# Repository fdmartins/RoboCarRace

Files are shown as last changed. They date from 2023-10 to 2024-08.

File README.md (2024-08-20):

# Construção de um Carro Autônomo - RoboCarRace
Veiculo Autonomo OpenSource

Este é o repositório oficial do RoboCar Race, o objetivo é disponibilizar dicas, circuitos e códigos para que você construa seu veículo autônomo em escala do zero.

* Conheça mais sobre a competição em:  
https://www.robocarrace.com.br/

* Veja os vídeos detalhados da construção do carro na playlist do YouTube: 
https://www.youtube.com/playlist?list=PLqjsxWOL0TM39jP3NmErrgpj0gdBl9_DG

### Divisão do projeto
Este projeto está separado por funcionalidades. 
- Parte 1: Codigo para comunicar com multiplos sensores de ultrassom genérico HC-SR04
- Parte 2: Codigo para controlar um servo motor, geralmente usado para o controle de direção em carros de radio controle.
- Parte 3: Codigo para controlar uma controladora ESC. O ESC é um dispositivo usado para controlar motores do tipo brushless (sem escovas) de 3 fios.
- Parte 4: Este código serve para coletar dados da pista. É feito um video e um arquivo csv. Cada linha o CSV é um frame e a posição da direção, velocidade e leituras de distancia do ultrassom.
- Parte 5: Este codigo é uma versão funcional que usa segmentação simples da pista, roda apenas em nivel de CPU, portanto, em qualquer plataforma como Raspberry Pi.

### Problemas de leitura/ruídos com o sensor de ultrassom?
veja este vídeo: https://www.youtube.com/watch?v=t73wGzd_4aE

---
### Custos da Plataforma básica:
- Chassis Usado Escala 1/8 (com servo e sem motor) : R$ 600,00
- Motor Brushless 3670 2150KV Genérico: R$ 109,12
- ESC 120A Genérico: R$ 87,15
- Sensor de Ultrassom HC-SR04: R$ 15,00 (cada unidade)
- Step Down Ajustável Dc/dc 5A C/ Display Xl4015: R$ 30,00
- Raspberry Pi PICO RP2040: R$ 59,00
- Conversor de Nível Lógico Bidirecional de 4 canais: R$ 8,00
- Rádio Controle + Receptor FlySky FSGT3B (opcional, mas útil para treinamento e testes): R$ 400,00
- Bateria Lipo 2500mah 3s 11.1v 40c:  R$ 190,00

Total da plataforma: R$ 1.528,27
Total sem rádio controle: R$ 1.128,27

## Custos com Placa de controle
- Nvidia® Jetson Nano 2gb Developer Kit Versão s/ Wifi: R$ 850,00

Custo Total Completo: R$ 2.378,27

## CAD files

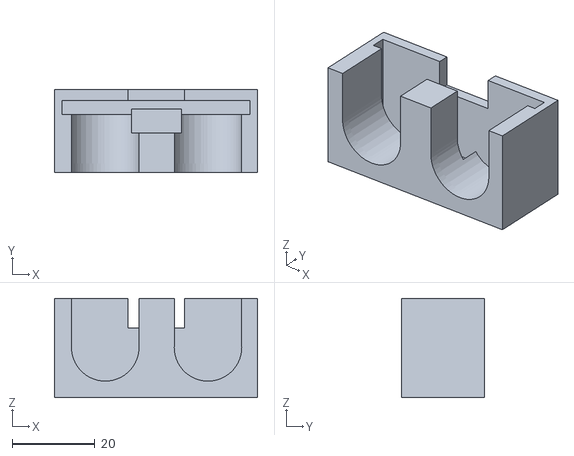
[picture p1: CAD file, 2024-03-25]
Parte 1 - Sensor Ultrassom/caixa_hcsr04_stl_3d.stl
49.0 x 20.0 x 24.0

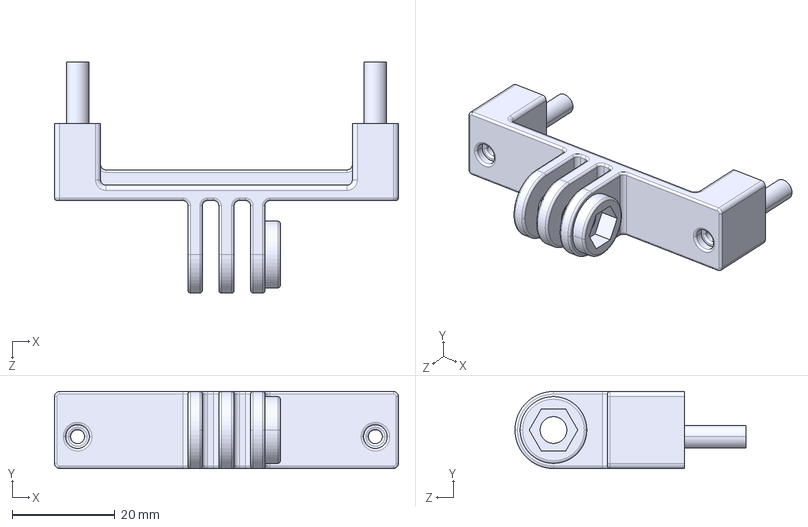
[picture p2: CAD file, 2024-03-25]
STLs - Impressão 3D/jetsoncamera/files/Camera_Mount.STEP
67.0 x 15.0 x 45.0 mm

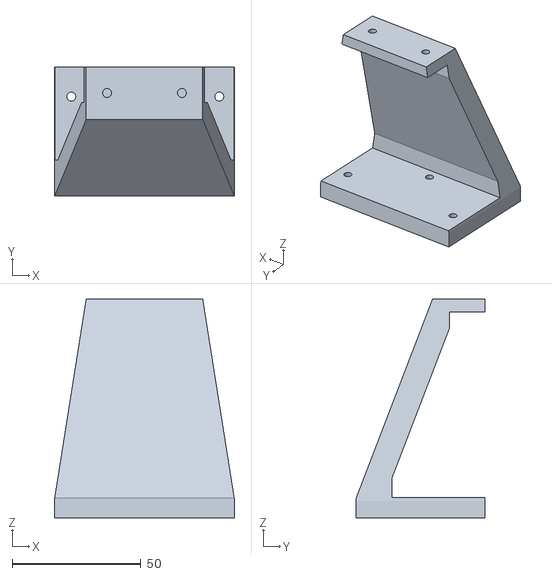
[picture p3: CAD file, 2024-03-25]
STLs - Impressão 3D/suporte_camera_3dprinter.stl
70.0 x 50.0 x 85.0

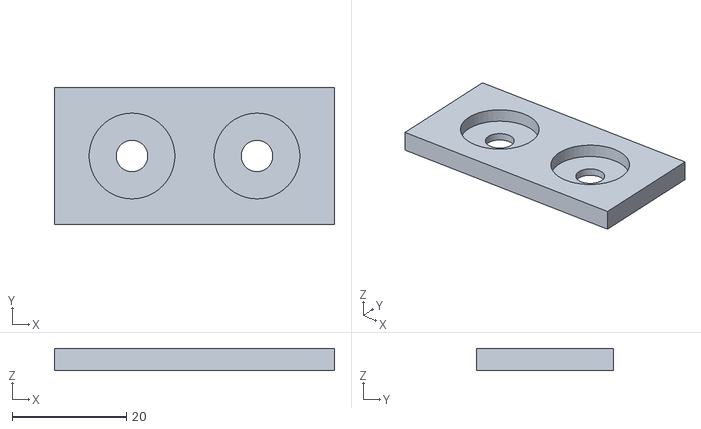
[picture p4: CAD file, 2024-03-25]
Parte 1 - Sensor Ultrassom/suporte_amortecedor_ultrassom.stl
49.0 x 24.0 x 3.90

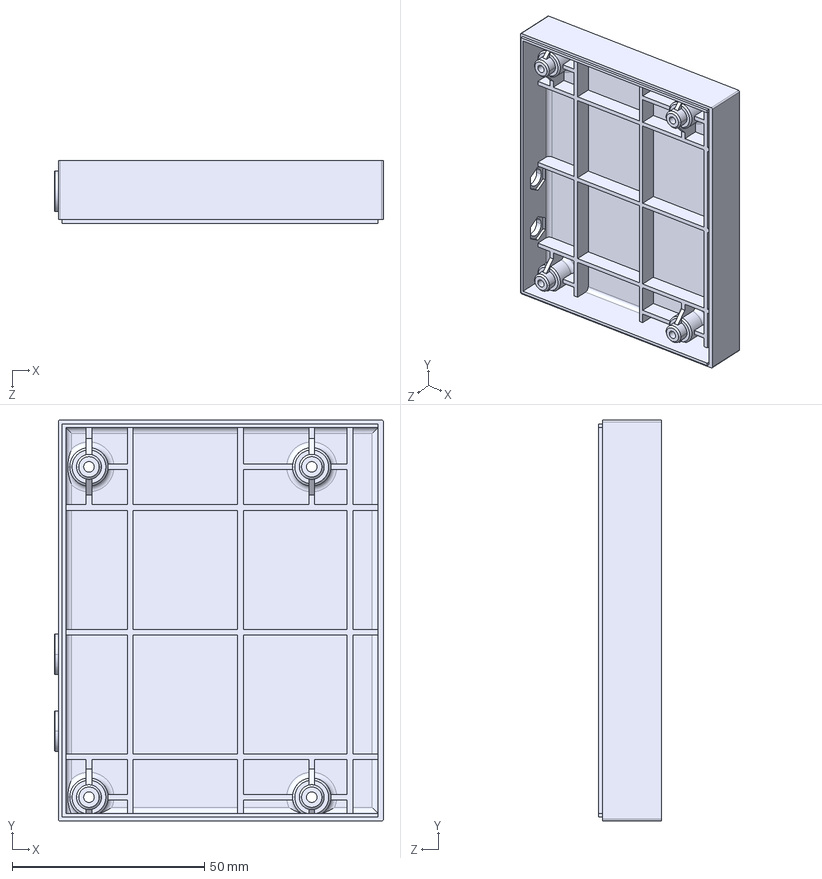
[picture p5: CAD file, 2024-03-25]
STLs - Impressão 3D/jetsoncamera/files/Case_Bottom.STEP
85.7 x 104.4 x 16.4 mm

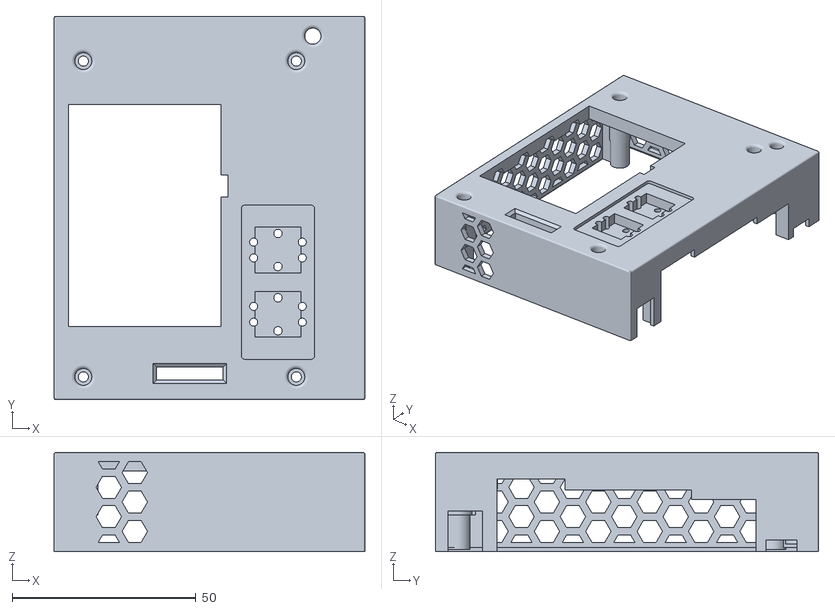
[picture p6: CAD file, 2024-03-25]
STLs - Impressão 3D/jetsoncamera/files/Case_topJetson_Case.STL
84.7 x 104.4 x 27.0

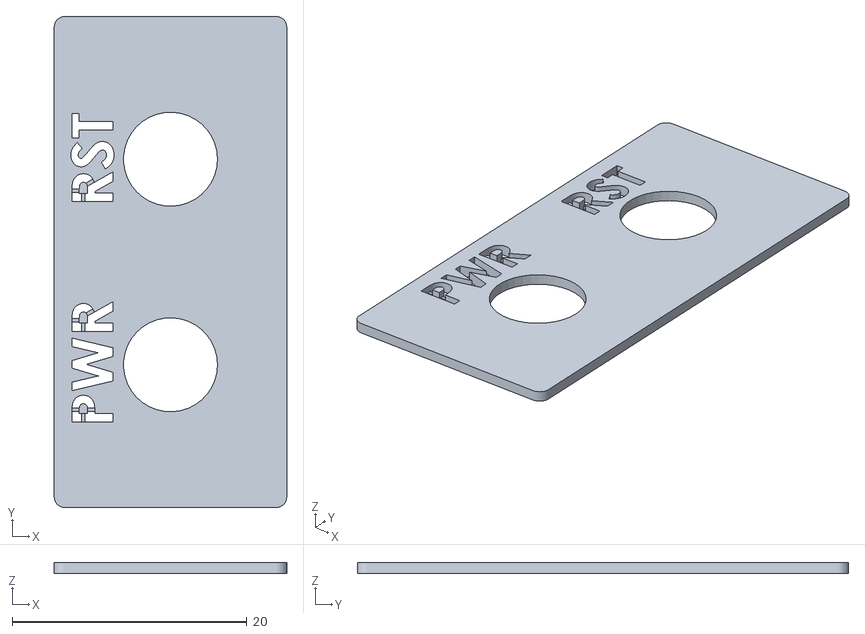
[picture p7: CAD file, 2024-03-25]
STLs - Impressão 3D/jetsoncamera/files/labelJetson_Case.STL
19.8 x 41.8 x 0.9

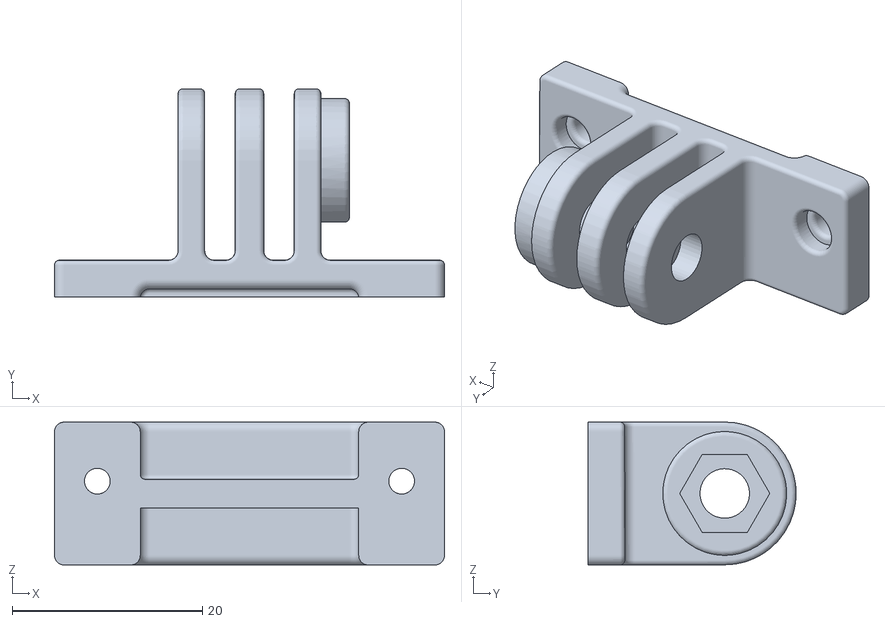
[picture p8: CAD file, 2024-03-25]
STLs - Impressão 3D/jetsoncamera/files/Camera_mount2.stl
41.0 x 21.9 x 15.0

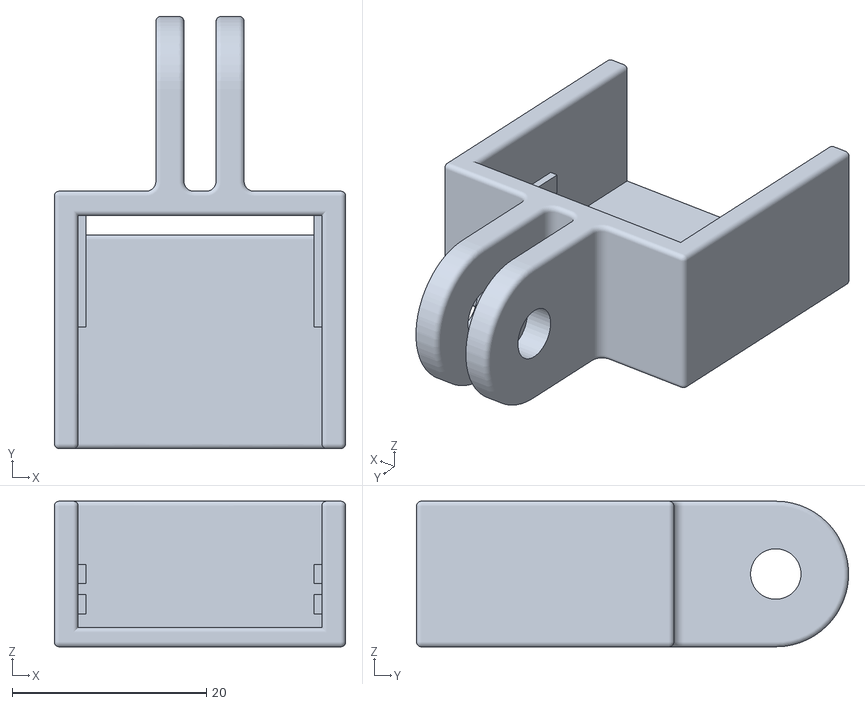
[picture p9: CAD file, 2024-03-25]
STLs - Impressão 3D/jetsoncamera/files/Camera_frameJetson_Case.STL
30.0 x 44.5 x 15.0

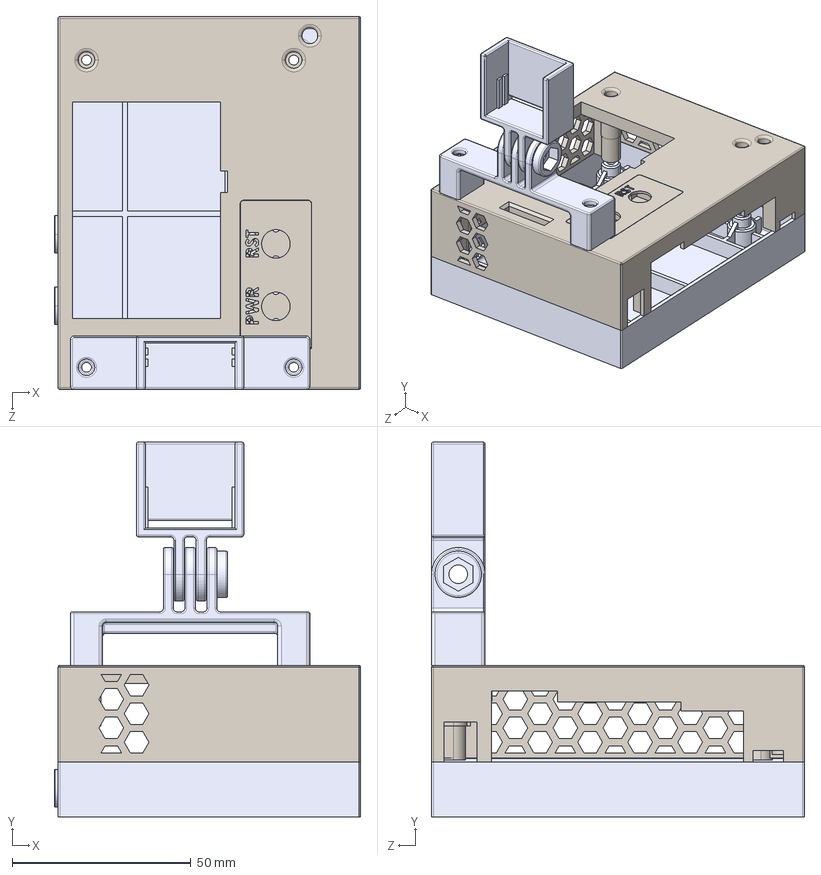
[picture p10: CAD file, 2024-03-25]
STLs - Impressão 3D/jetsoncamera/files/Jetson_Case.STEP
85.7 x 104.9 x 104.4 mm
Case_bottom^Jetson Case
Case_top^Jetson Case
Button_label^Jetson Case
Camera_mount^Jetson Case
Camera_frame^Jetson Case

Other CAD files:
STLs - Impressão 3D/jetsoncamera/files/Camera_mountJetson_Case.STL
STLs - Impressão 3D/jetsoncamera/files/Case_Label.STEP
STLs - Impressão 3D/jetsoncamera/files/Case_bottomJetson_Case.STL
STLs - Impressão 3D/jetsoncamera/files/Case_Top.STEP
STLs - Impressão 3D/jetsoncamera/files/Camera_Frame.STEP

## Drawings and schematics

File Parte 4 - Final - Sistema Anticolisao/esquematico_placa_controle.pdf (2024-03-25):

## PARACHOQUE

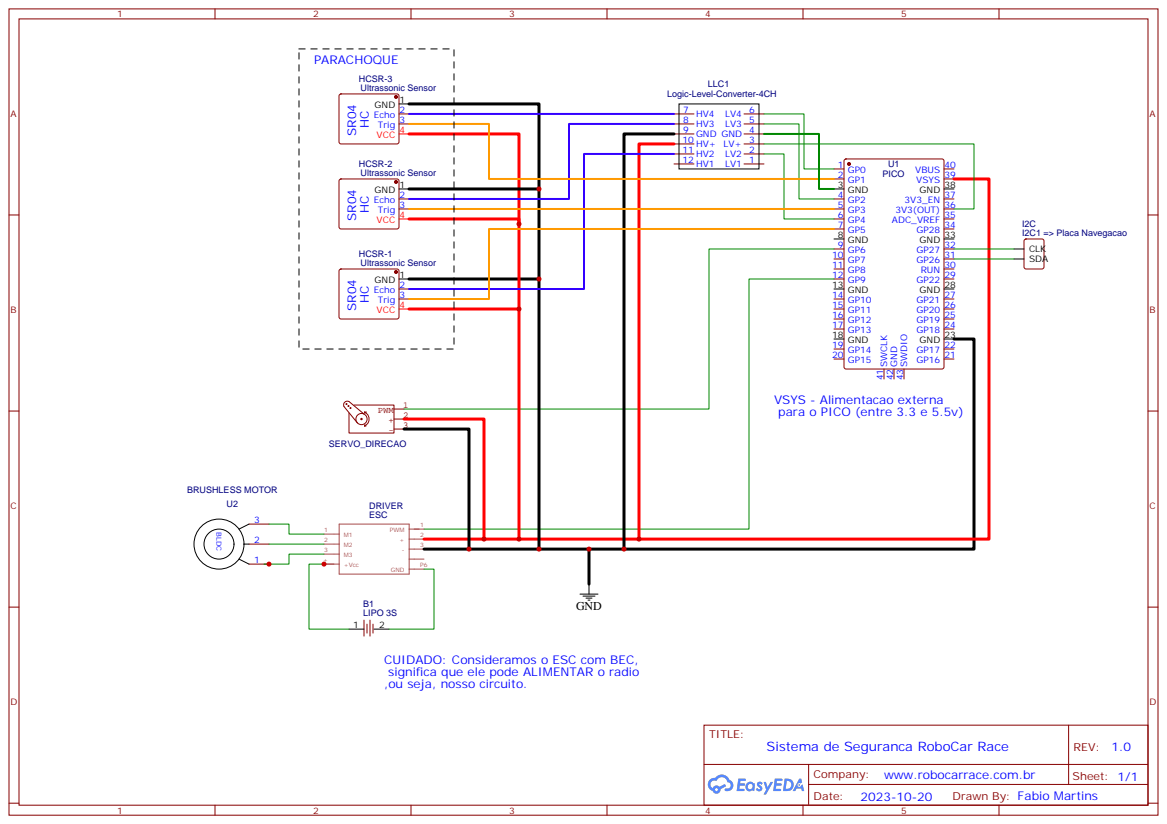
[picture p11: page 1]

CUIDADO: Consideramos o ESC com BEC,
significa que ele pode ALIMENTAR o radio
,ou seja, nosso circuito.

Company: www.robocarrace.com.br

Drawn By: Fabio Martins

## VSYS - Alimentacao externa para o PICO (entre 3.3 e 5.5v)

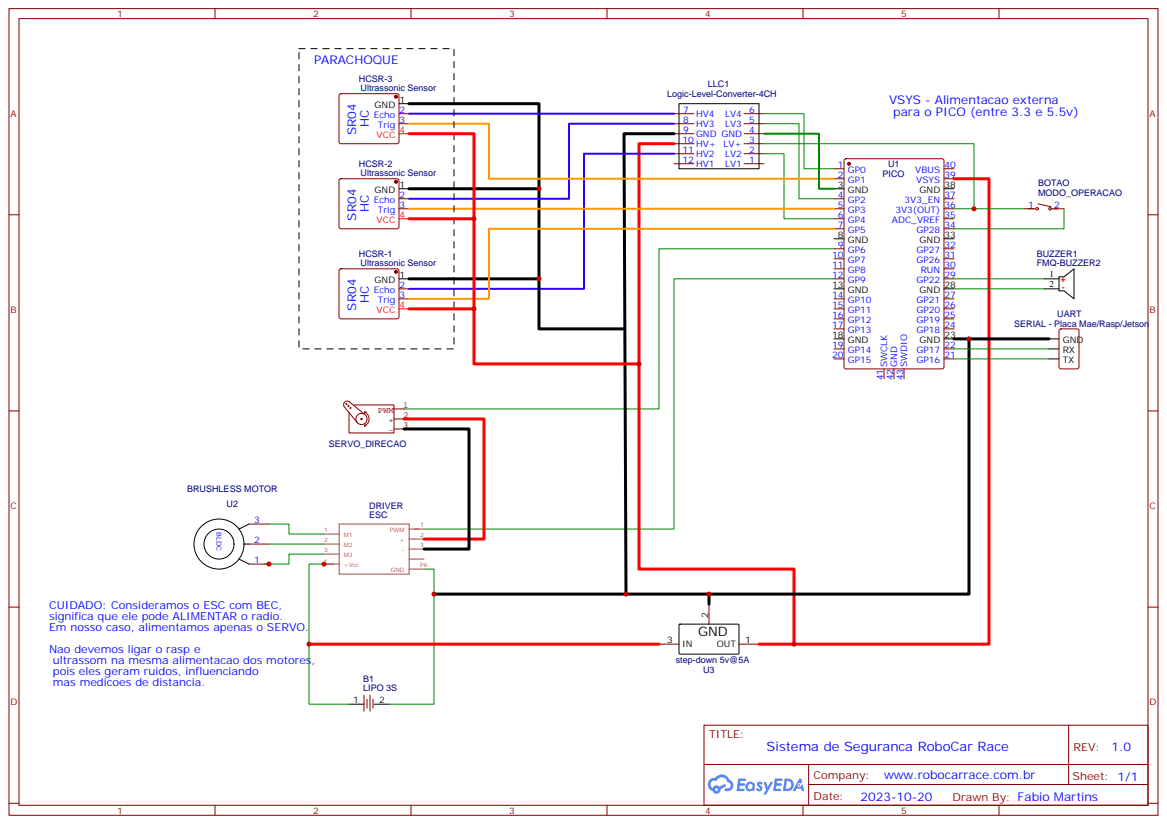
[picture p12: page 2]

SERIAL - Placa Mae/Rasp/Jetson

CUIDADO: Consideramos o ESC com BEC,
significa que ele pode ALIMENTAR o radio.
Em nosso caso, alimentamos apenas o SERVO.
Nao devemos ligar o rasp e
ultrassom na mesma alimentacao dos motores,
pois eles geram ruidos, influenciando

Company: www.robocarrace.com.br

Drawn By: Fabio Martins

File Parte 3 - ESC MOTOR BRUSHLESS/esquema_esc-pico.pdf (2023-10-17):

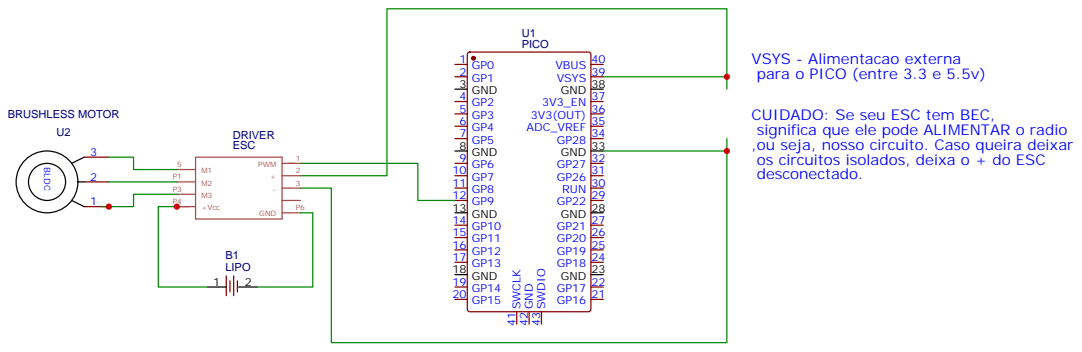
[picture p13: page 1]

CUIDADO: Se seu ESC tem BEC,
significa que ele pode ALIMENTAR o radio
,ou seja, nosso circuito. Caso queira deixar
os circuitos isolados, deixa o + do ESC
desconectado.

Company: www.robocarrace.com.br

Drawn By: F bio Martins

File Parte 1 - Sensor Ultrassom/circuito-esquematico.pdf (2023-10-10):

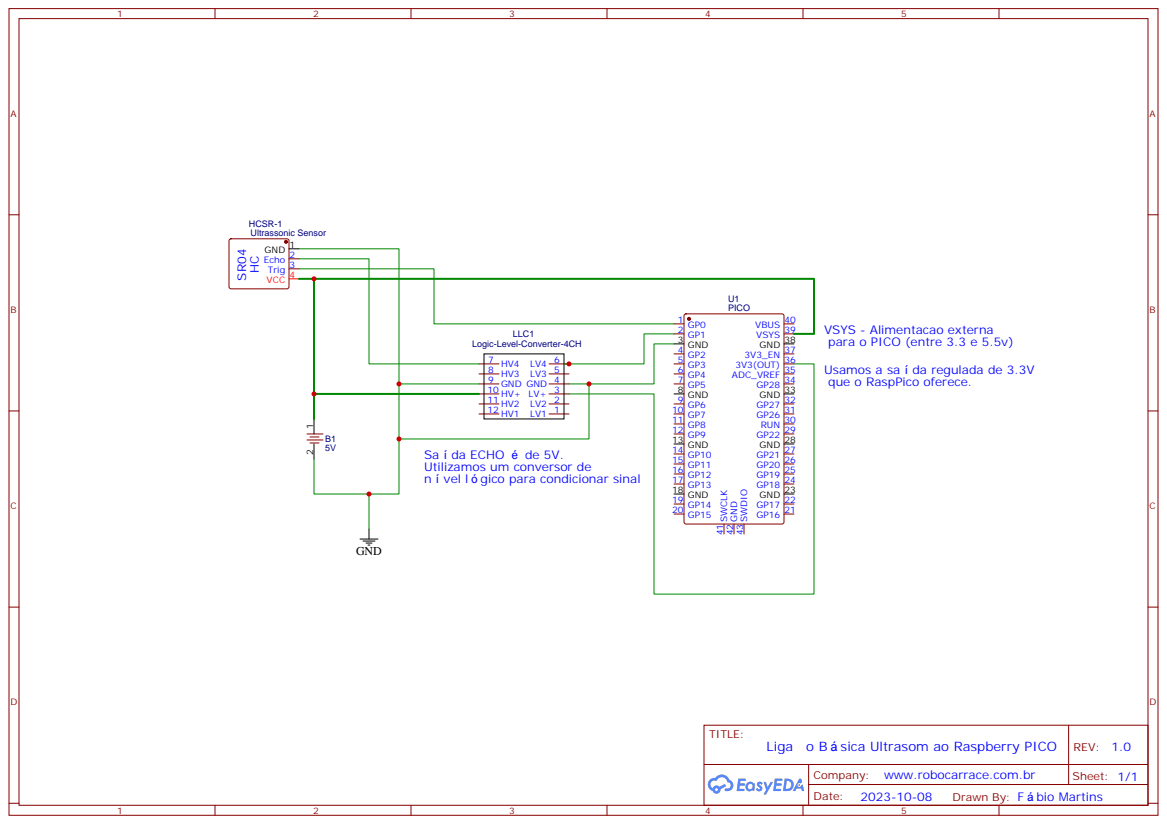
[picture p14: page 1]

Usamos a sa da regulada de 3.3V
que o RaspPico oferece.

Utilizamos um conversor de
n vel l gico para condicionar sinal

Company: www.robocarrace.com.br

Drawn By: F bio Martins

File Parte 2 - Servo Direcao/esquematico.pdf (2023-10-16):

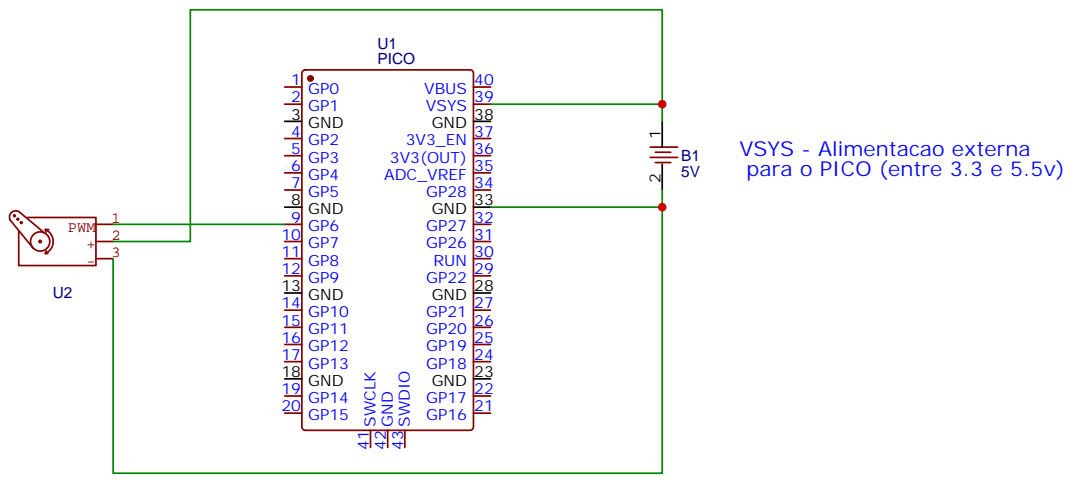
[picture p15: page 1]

Company: www.robocarrace.com.br

Drawn By: F bio Martins

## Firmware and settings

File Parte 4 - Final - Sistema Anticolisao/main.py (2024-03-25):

# fabio martins
# 20 out 2023 
# https://github.com/fdmartins/RoboCarRace

from machine import Pin, PWM, I2C
import utime
import time
import _thread


class Servo:
    __motor = None
    __servo_pwm_freq = 50
    __min_u16_duty = 3300  # 1ms min cycle 
    __max_u16_duty = 6600  # 2ms max cycle
    min_angle = 0
    max_angle = 180 
    current_angle = 0.001


    def __init__(self,  min_angle, max_angle, pin):
        self.min_angle = min_angle
        self.max_angle = max_angle
        self.__initialise(pin)


    def move(self, angle):
        # Arredondamos para comparacao
        angle = round(angle, 2)
        # precisa mover?
        if angle == self.current_angle:
            return
        self.current_angle = angle
        # calculamos novo duty cicle.
        duty_u16 = self.__angle_to_u16_duty(angle)
        self.__motor.duty_u16(duty_u16)

    def __angle_to_u16_duty(self, angle):
        # esta funcao calculo o duty cicle proporcional em relacao aos angulos minimo a maximo e os dutys min e max.
        return int((angle - self.min_angle) * self.__angle_conversion_factor) + self.__min_u16_duty


    def __initialise(self, pin):
        self.current_angle = -0.001
        self.__angle_conversion_factor = (self.__max_u16_duty - self.__min_u16_duty) / (self.max_angle - self.min_angle)
        self.__motor = PWM(Pin(pin))
        self.__motor.freq(self.__servo_pwm_freq)
        
class Ultrassom:

    def __init__(self,  trigger_pin, echo_pin):
        self.trigger = Pin(trigger_pin, Pin.OUT) #GPIO
        self.echo = Pin(echo_pin, Pin.IN) 
        self.distance = 0

    def get_distance(self):
        # retorna ultima lida.
        return self.distance

    def read(self):
        # lemos a distancia.

        # acionamos o trigger, precisa ser de 10us, mas o tempo da funcao em micropython eh lenta, por isso consideramos 2.
        # https://www.robot-electronics.co.uk/htm/srf05tech.htm
        utime.sleep_us(2)
        self.trigger.high()
        utime.sleep_us(2)
        self.trigger.low()

        
        signaloff = signalon = 0
        start = utime.ticks_us()
        timeout = False
        
        while self.echo.value() == 0:
            signaloff = utime.ticks_us()
            if (start - signaloff)>40000:
                #timeout - limite para nao ficar preso no looping.
                timeout = True
                break
            
        while self.echo.value() == 1:
            signalon = utime.ticks_us()
            if (signalon - signaloff)>40000:
                #timeout - limite para nao ficar preso no looping.
                timeout = True
                break

        timepassed = signalon - signaloff
        
        # distancia em cm
        # velocidade do som 340 m/s
        distance = (timepassed * 0.0340) / 2.0 
        

        if timeout:
            distance = 0    
        
        #print(timeout, timepassed, distance)
        
        
        if distance<5 or distance>500:
            # erros medicao.
            self.distance = 0
            
        
        self.distance = distance


class ReadPWM:
    def __init__(self, pin, min_value, max_value ):
        self.pin = Pin(pin, Pin.IN)  #GPIO
        self.min_value = min_value
        self.max_value = max_value

        # tempo minimo 1000us
        # tempo maximo 2000us.
        self.min_duty = 1000
        self.max_duty = 2000
        self.__conversion_factor =  (self.max_value - self.min_value) / (self.max_duty - self.min_duty)

    def read(self):
        # espera sinal cair.
        while self.pin.value() == 1: 
            pass

        # espera sinal levantar.
        while self.pin.value() == 0: 
            pass

        start = utime.ticks_us()

        # espera sinal cair.
        while self.pin.value() == 1: 
            pass
        
        end = utime.ticks_us()

        timepassed = end - start
        

        return int((timepassed - self.min_duty) * self.__conversion_factor) + self.min_value

###########################
######## INICIAMOS ########
###########################

led_onboard = machine.Pin(25, machine.Pin.OUT)

motor_tracao = Servo(
        min_angle=-100, #  correspondendo a 100% da velocidade de ré
        max_angle=100, #  correspondendo a 100% da velocidade de frente.
        pin=9  # ajuste com o pino GPIO que esta ligado o sinal do ESC
    )  


servo_dir = Servo(
        min_angle=-45, 
        max_angle=45, # utilizamos um servo de 90 graus. Ajuste conforme o que vc usa.
        pin=6 
    )  

ultrassom_left = Ultrassom(
    trigger_pin=0,
    echo_pin=1
)

ultrassom_center = Ultrassom(
    trigger_pin=2,
    echo_pin=3
)

ultrassom_right = Ultrassom(
    trigger_pin=4,
    echo_pin=5
)

pwm_input_servo_dir = ReadPWM(
    pin=21,
    min_value = -45,
    max_value = 45
)

pwm_input_motor_tracao = ReadPWM(
    pin=20,
    min_value = -100,
    max_value = 100
)


#I2C_ADDRS=0x18
#i2c = I2C(
#    I2C_ADDRS, 
#    scl=Pin(27), 
#    sda=Pin(26), 
#    freq=100000)


##################################################################
######        LOOPING VERIFICACAO DISTANCIA SEGURANCA     ########
##################################################################

def task_ultrasound():
    while True:
        ultrassom_left.read()
        ultrassom_center.read()
        ultrassom_right.read()
        time.sleep(1.05)

# iniciamos a thread.
# https://bytesnbits.co.uk/multi-thread-coding-on-the-raspberry-pi-pico-in-micropython/
_thread.start_new_thread(task_ultrasound, ())

#################################
###### LOOPING PRINCIPAL ########
#################################

# ao ligar, o ESC precisa ser iniciado.
# para isso colocamos a velocidade em NEUTRO.
motor_tracao.move(0)
# aguardamos o ESC iniciar.
time.sleep(5)

print("INICIADO")

while True:
    
    if False:
        # Verificamos placa principal enviou alguma mudanca.
        # TODO
        pass
    else:
        # ou se modo treinamento, lemos do receptor/pwms
        pass

    speed = 10
    steerwheel = 0

    # verificamos se estamos com delay na recepcao dos dados.
    # TODO.

    # verificamos se existe colisao.
    
    if ultrassom_left.get_distance() < 100000:
        speed = 5
        steerwheel = 45
        #print("SENSOR COLISAO ESQUERDO: " ,  ultrassom_left.get_distance())

    if ultrassom_right.get_distance() < 100000:
        speed = 5
        steerwheel = -45
        #print("SENSOR COLISAO DIREITO: " , ultrassom_right.get_distance())

        
    if ultrassom_center.get_distance() < 100000:
        speed = 0
        #print("SENSOR COLISAO CENTRAL: " , ultrassom_center.get_distance())

    # ajustamos direcao.
    servo_dir.move(steerwheel)
    
    # ajustamos velocidade.
    motor_tracao.move(speed)

    led_onboard.toggle()
    time.sleep(0.1)

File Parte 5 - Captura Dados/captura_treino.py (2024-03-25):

# -*- coding: iso-8859-1 -*-

# Fabio Martins - interapix.com.br
# 03/11/2023
 
# PARA AUTO START VER: 
# https://askubuntu.com/questions/133235/how-do-i-allow-non-root-access-to-ttyusb0
# https://forums.developer.nvidia.com/t/jetson-nano-auto-run-python-code-when-power-up/108999
# https://unix.stackexchange.com/questions/225401/how-to-see-full-log-from-systemctl-status-service


import enum
#import smbus # apt-get install python-smbus
import time 
from threading import Thread 
import serial
import csv

import cv2

import time
import threading
import datetime 
import numpy as np

#import imp
#import inputs 
import threading

import Adafruit_SSD1306   # pip3 install Adafruit-SSD1306
from PIL import Image
from PIL import ImageDraw
from PIL import ImageFont


class DisplaySSD1306:
    def __init__(self):
        # 128x32 display with hardware I2C:
        # setting gpio to 1 is hack to avoid platform detection
        self.disp = Adafruit_SSD1306.SSD1306_128_32(rst=None, i2c_bus=1, gpio=1)

        # Initialize library.
        self.disp.begin()

        # Clear display.
        self.disp.clear()
        self.disp.display()

        #Load default font.
        self.font = ImageFont.load_default()
   
        # Create blank image for drawing.
        # Make sure to create image with mode '1' for 1-bit color.
        self.width = self.disp.width
        self.height = self.disp.height
        self.image = Image.new('1', (self.width, self.height))

        # Get drawing object to draw on image.
        self.draw = ImageDraw.Draw(self.image)

        # Draw a black filled box to clear the image.
        self.draw.rectangle((0, 0, self.width, self.height), outline=0, fill=0)

        self.draw.text((0,0), "Aguardando Pico...", font=self.font, fill=255)

        self.disp.image(self.image)
        self.disp.display()

    def write(self, x,y, text, clear=True):

        if clear:
            # Draw a black filled box to clear the image.
            self.draw.rectangle((0, 0, self.width, self.height), outline=0, fill=0)

        self.draw.text((x, y), text, font=self.font, fill=255)

        # Display image.
        # Set the SSD1306 image to the PIL image we have made, then dispaly
        self.disp.image(self.image)
        self.disp.display()

class CarComm:
    def __init__(self, serialPort, baudrate = 115200):
        self.running = True
        self.serial = serial.Serial(
            port = serialPort, 
            baudrate = baudrate, stopbits=1, timeout=100)  
              
        self.thread = threading.Thread(target = self.update)

        self.mode = 0
        self.speed = 0
        self.steer = 0
        self.sonar_r = 0
        self.sonar_c = 0
        self.sonar_l = 0

        self.last_comm = datetime.datetime.now()

        self.data_length_tx = 2
        self.data_length_rx = 6
        
        self.start_byte = "*"
        self.end_byte = "\n"

        self.thread.start()
        
    def stop(self):
        self.running = False

    def get_speed(self):
        return self.speed
    def get_steer(self):
        return self.steer
    def set_speed(self, v):
        self.speed = v
    def set_steer(self,v):
        self.steer = v


    def isOnline(self):
        if (datetime.datetime.now()-self.last_comm).total_seconds()<2:
            return True
        return False

    def update(self):

        data = self.serial.read(self.serial.inWaiting())
        print("garbage collection:", len(data))

        while self.running:

            #if(self.speed>100):
            #    self.speed=-100
            #self.speed+=1
            #self.steer=100-self.speed
            
            try:
                # enviamos a velocidade e direcao.
                package = [
                            
                            str(self.speed),
                            str(self.steer),
                           
                        ]

                data_tx = self.start_byte + ('|'.join(package)) +  self.end_byte

                data_tx = data_tx.encode()
                #print(data_tx)
                self.serial.write(data_tx)
                
                #print("enviado >>>> ", data_tx)
                
                while(self.serial.inWaiting()<13):
                    # TODO TIMEOUT
                    pass
                
                
                # lemos todos os bytes no buffer da serial...
                data = self.serial.readline()

                #print("recebido <<< ", data)
                
                if len(data)<3:
                    continue

                data = data.decode("UTF-8")


                if data[0]==self.start_byte and data[-1]==self.end_byte:
                    info = data[1:-1].split('|')
                    #print(info)
                    if len(info)==self.data_length_rx:
                        #print(datetime.datetime.now(), info)
                        self.mode = int(info[0])
                        self.speed = int(info[1])
                        self.steer = int(info[2])
                        self.sonar_l = int(info[3])
                        self.sonar_c = int(info[4])
                        self.sonar_r = int(info[5])
                        
                self.last_comm = datetime.datetime.now()

                time.sleep(0.01)


            except Exception as err:
                print("Erro")
                print(err)


class Camera:
    def __init__(self):
        print(self.gstreamer_pipeline(flip_method=0))
        self.cap = cv2.VideoCapture(self.gstreamer_pipeline(flip_method=0), cv2.CAP_GSTREAMER)

        if self.cap.isOpened():
            ret_val, img = self.cap.read()
            if ret_val==False:
                print("Sem Camera Encontrada") 
                exit()
        else:
            print("Sem Camera Encontrada")  
            exit()

    def gstreamer_pipeline(self,
        capture_width=1280,
        capture_height=720,
        display_width=640,
        display_height=360,
        framerate=120,
        flip_method=0,
        ):
        return (
            "nvarguscamerasrc ! "
            "video/x-raw(memory:NVMM), "
            "width=(int)%d, height=(int)%d, "
            "format=(string)NV12, framerate=(fraction)%d/1 ! "
            "nvvidconv flip-method=%d ! "
            "video/x-raw, width=(int)%d, height=(int)%d, format=(string)BGRx ! "
            "videoconvert ! "
            "video/x-raw, format=(string)BGR ! appsink drop=1"
            % (
                capture_width,
                capture_height,
                framerate,
                flip_method,
                display_width,
                display_height,
            )
        )

    def get_frame(self):
        if self.cap.isOpened():
            ret_val, img = self.cap.read()
            if ret_val==False:
                print("Falha Camera") 
                exit()

            return img
        else:
            print("Sem Camera Encontrada")
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

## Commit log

2023-10-10 código e circuito esquemático iniciais do sensor de ultrassom.
2023-10-16 versao exemplo do controle de servo utilizando PWM
2023-10-17 programa básico exemplo controle ESC do motor brushless
2024-03-25 Versão que correu no RoboCar 2023. Segmentação Simples de Imagem.
    [Camera_Frame.STEP, Camera_Mount.STEP, Camera_frameJetson_Case.STL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]
